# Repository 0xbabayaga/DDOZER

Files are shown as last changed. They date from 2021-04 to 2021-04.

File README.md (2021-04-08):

# DDOZER
Peristaltic dosing pump for DIY. 
Developed firmware is suitable for dosing elements in to the reef aquarium (dosing CA/ALK/MG/NO3/PO4/LiquidFOOD).
Can be easily used for other dosing process.

<b>Technical details:</b>
 - stepper motor & multystep control
 - precise - 0.1ml
 - flow rate (depends on currently option selected) - 6/24/50 ml per minute
 - dimension 52 x 60 x 93mm
 - power 12V DC / 0.2 ... 2.5A (depending on motor type)
 - acrylic body
 - suitable for tubes size from 4 to 5mm outer diameter
 - nonvolatile built-in RTC
 - acryll body (from 2mm thiсkness material)

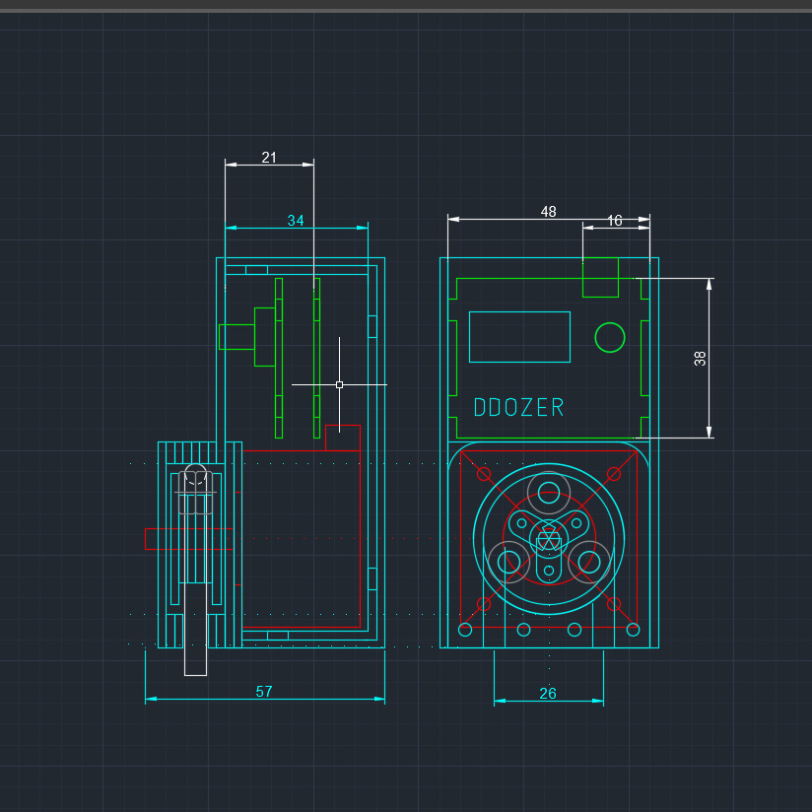
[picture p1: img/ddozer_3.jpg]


<b>Functionality:</b>
 - daily programmble dosign schedule (start dosing time / end dosing time / dosing volume / portions count)
   DDozer automatically divides necessary Volume and dosing interval to Portions count set and doses it evenly. 
   So start first dosage is started at Start Dosing Time & last dosage is completed at the End Dosing Time. Each portion of the volume equal to Dosing Volume / Portions count.     
 - calibration & verify
   User can calbrate and/or verify DDozer any time
 - all DDozer settings saved in nonvolatile memory
 - calculates and saves dosing statistics calculates in nonvolatile memory (daily dosage / total device dosage / total motor hours / last calibration date)
 - daily overdosage protection

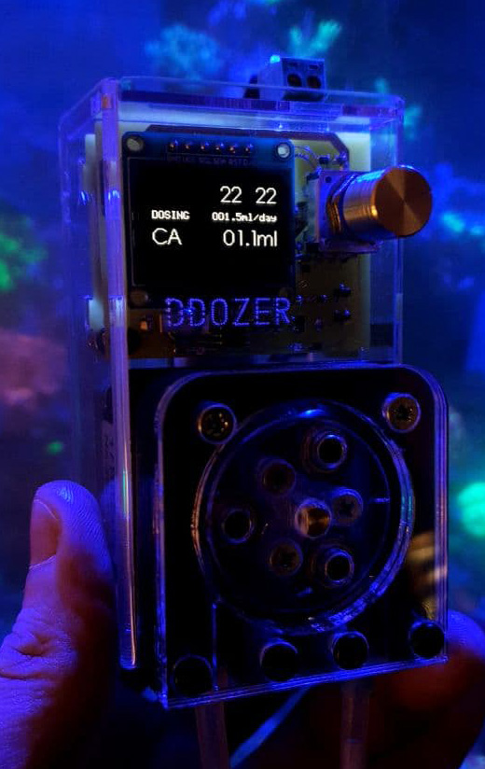
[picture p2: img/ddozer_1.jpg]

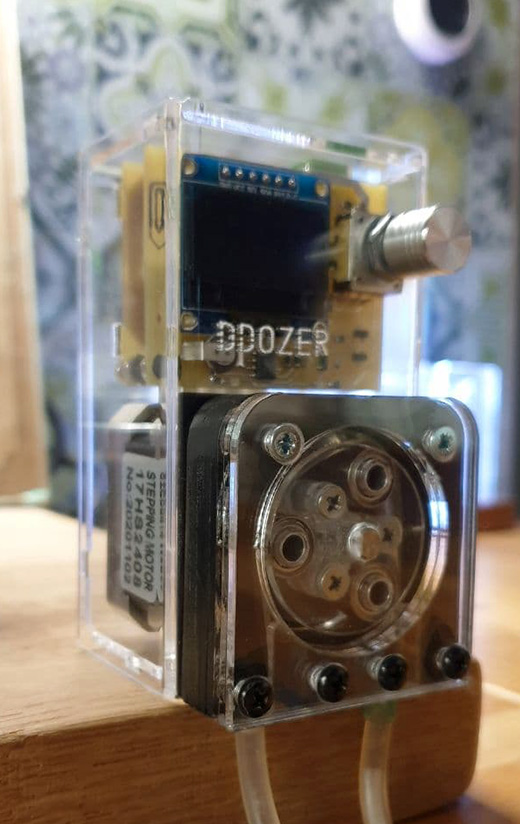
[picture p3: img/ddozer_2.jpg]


Based on STM8S105K4T6C, DRV8825 and SSD1306 OLED display.

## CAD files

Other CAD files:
drawing/DDOZER.dwg

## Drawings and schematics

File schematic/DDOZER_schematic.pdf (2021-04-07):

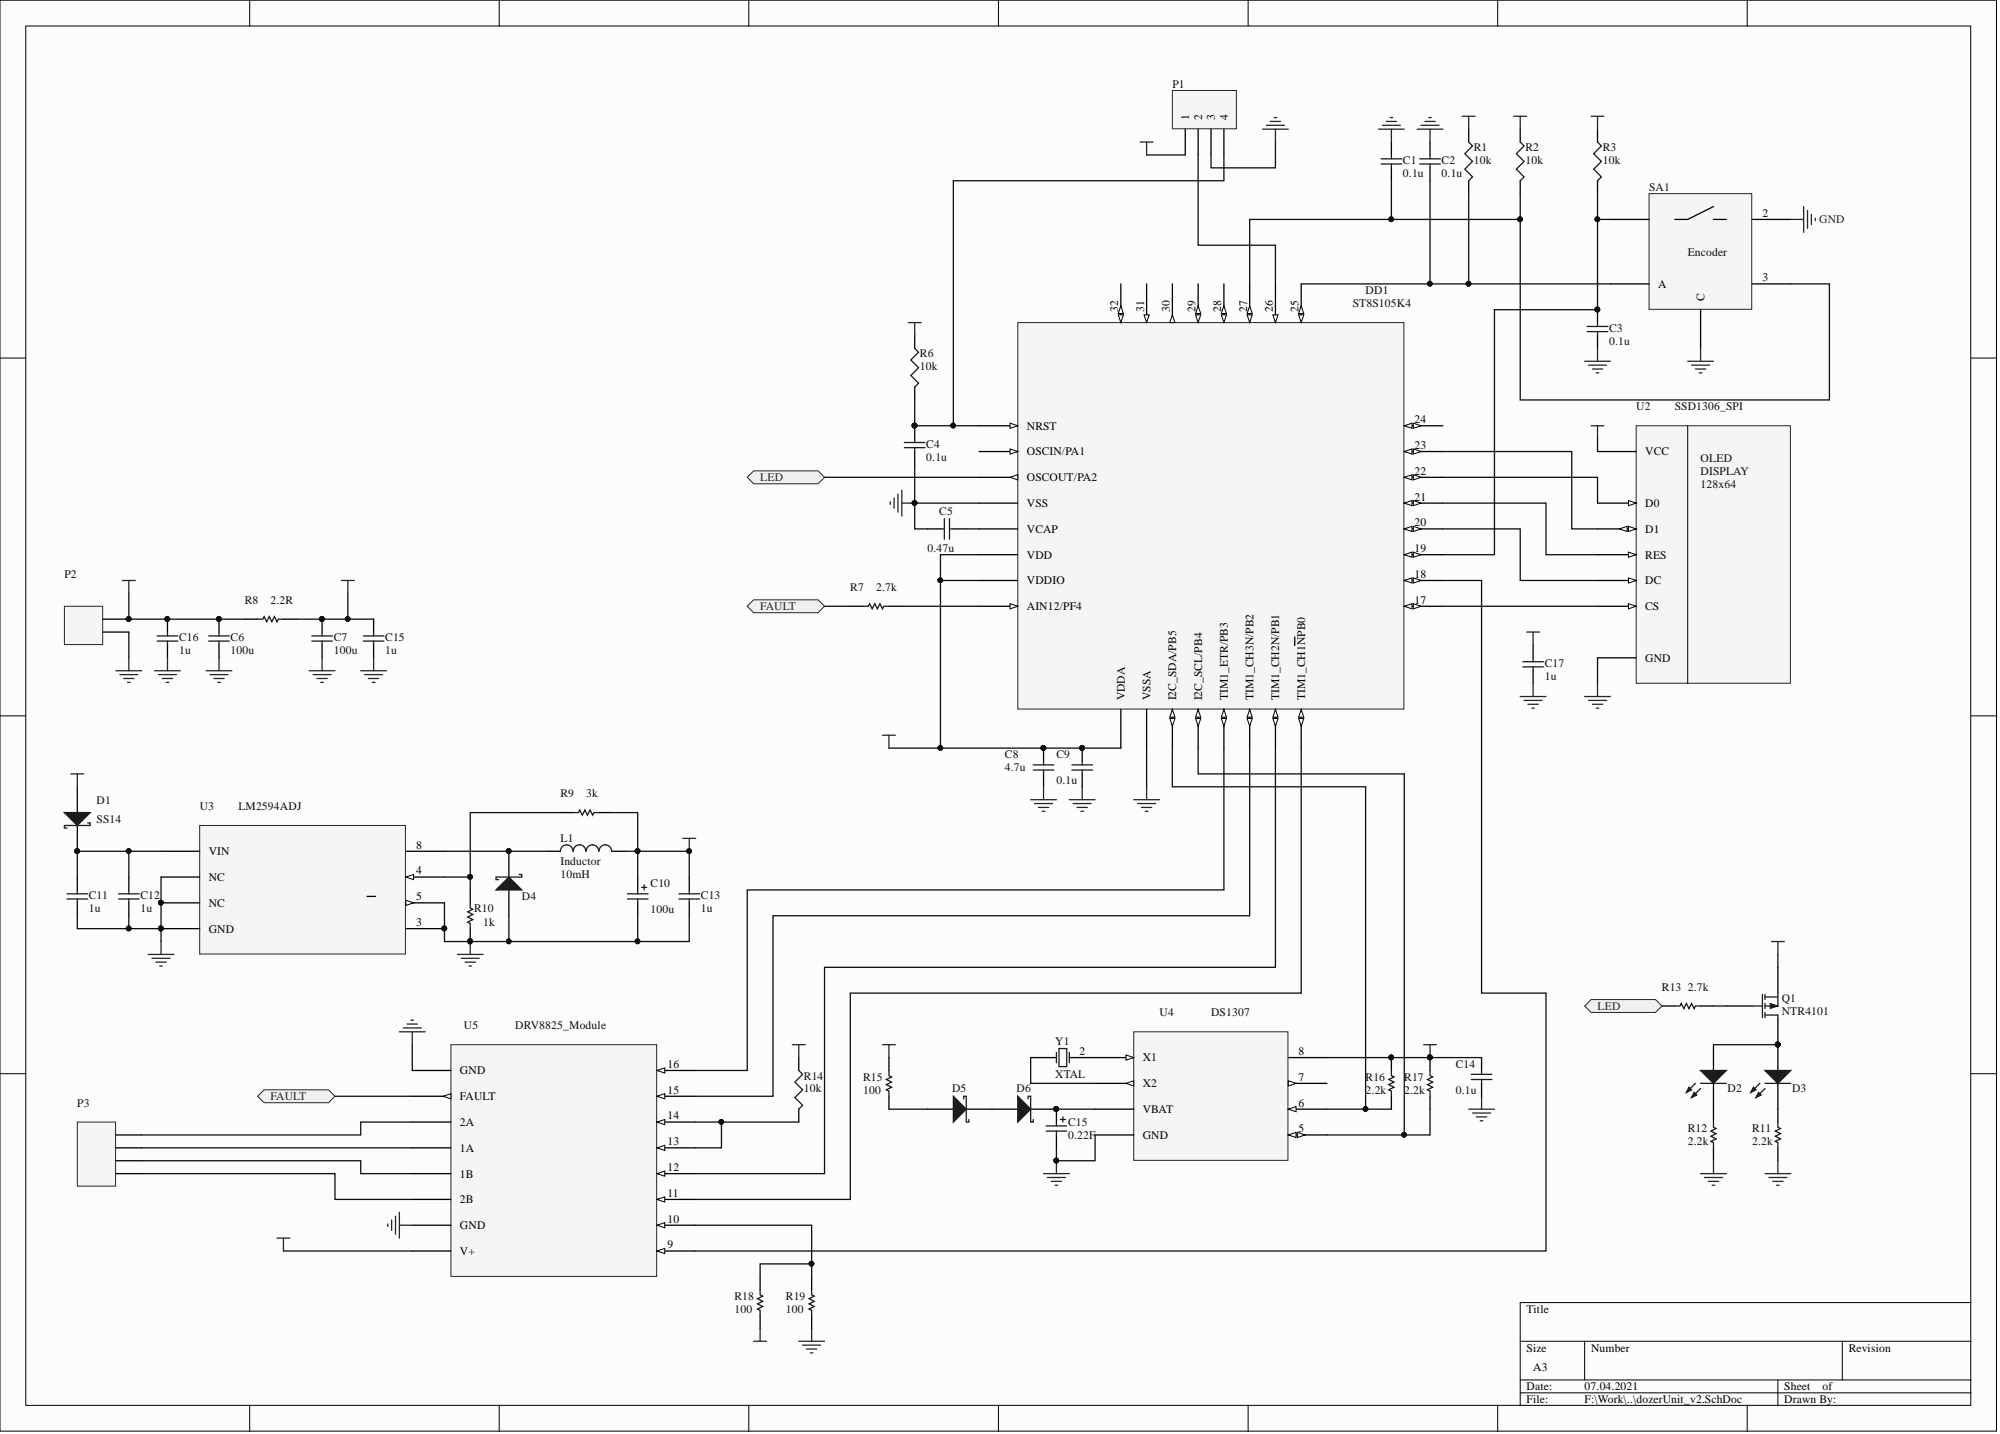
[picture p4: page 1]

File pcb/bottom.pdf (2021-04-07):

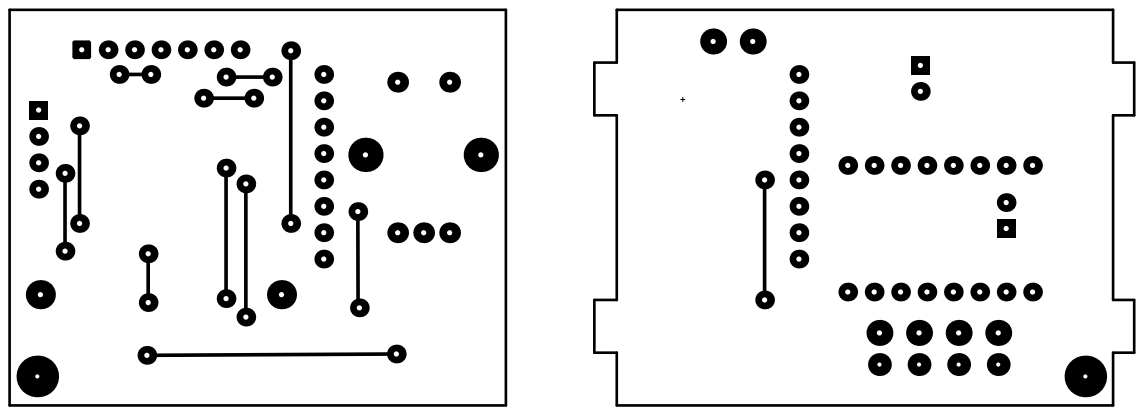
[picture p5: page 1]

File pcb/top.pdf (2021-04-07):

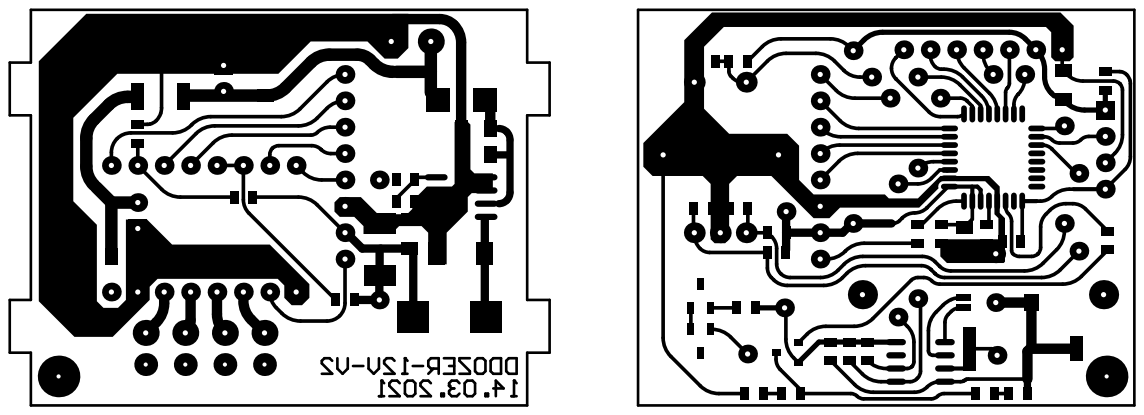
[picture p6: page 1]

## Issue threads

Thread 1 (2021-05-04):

replacement for STM8S105K4T6C

dodolcool, 2021-05-04:
Hello
im interest in building DDOZER really loved the design. the question is can i change the STM8S105K4T6C with the prebuild stm8s? (not the IC version but the prebuild like arduino nano version) since my soldering skill still on beginner and have no luck with the IC smd model.

thanks

Kamal

0xbabayaga, 2021-05-04:
Hello Kamal,

Of course if you re-create the same schematic (connection of MCU to other parts of design) with Arduino Nano STM8S series you will have the same working hardware.

dodolcool, 2021-05-04:
great i will try it soon :) one more question what type of stepper motor did u used?

0xbabayaga, 2021-05-05:
DRV8825 stepper driver allows you to connect a big enough variety of stepper motors.
I have used most popular motor which usually used in 3D-printing like NEMA 17 (1.8) 17HS2408 dimension

dodolcool, 2021-05-18:
thanks for your information. now i have basic question :D what program need to use to upload to stm? i tried with arduino IDE with stm plugin but not work >.<

im sorry for a lots of question

0xbabayaga, 2021-05-19:
Unfortunately i have never used Arduino products so i cannot help you

dodolcool, 2021-05-19:
what compiler program did you use to upload to stm?

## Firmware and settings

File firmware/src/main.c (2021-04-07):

#include "stm8s.h"
#include <stdio.h>
#include "../device/cpuinit.h"
#include "../device/utility.h"
#include "../drivers/ds1307.h"
#include "../drivers/drv8825.h"
#include "../drivers/ssd1306.h"
#include "../device/timers.h"
#include "../device/device.h"
#include "../device/encoder.h"
#include "../device/delay_us.h"
#include "core/task.h"
#include "core/menu.h"

static uint32   rtcReadTick = TIMER_500MS_TMT;
static uint32   menuTick = TIMER_100MS_TMT;
static bool     menuUpdate = TRUE;
static bool     timeChanged = FALSE;
static uint8    lastSecond = 0;

int main( void )
{    
    asm("sim");

    CPU_Init();
    TIM_Init();  
    DRV_Init();
    ENC_Init();
    SSD1306_Init();
    
    DRV_StopMotor();
    
    if (DS1307_init() == FALSE)
        DS1307_init();

    DS1307_readDateTime();

    DEV_ReadCfg();
    DEV_ReadStat(DS1307_getDateTime());
    DRV_SetMotorMode((eMotorSpeedMode) DEV_GetDevOptions()->speedPrecise, (eDir) DEV_GetDevOptions()->dir);

    SSD1306_Clear();
    SSD1306_DrawText16(0, 16, DEVICE_NAME, FALSE, eJustify_Center);
    SSD1306_DrawText8(0, 40, DEVICE_FIRMWARE_VER, eJustify_Center);
    delay_ms(1777);
    SSD1306_Clear();

    task_initActivity();
    resetUpTime();

    asm("rim");
    
    for(;;)
    {      
        /* Reading the system time */
        if (TIM_isTimeoutExpired(rtcReadTick, TIMER_500MS_TMT) == TRUE)
        {
            rtcReadTick = TIM_getSystemTick();
            
            DS1307_readDateTime();

            if (lastSecond != DS1307_getDateTime()->seconds)
            {
                lastSecond = DS1307_getDateTime()->seconds;
                timeChanged = TRUE;
            }
            
            //menuUpdate = TRUE;
        }      
        
        /* Display update */
        if (TIM_isTimeoutExpired(menuTick, TIMER_100MS_TMT) == TRUE)
        {
            menuTick = TIM_getSystemTick();
            menuUpdate = TRUE;
        }
        
        /* Menu handler */
        MENU_Activity(menuUpdate);
        menuUpdate = FALSE;

        if (timeChanged == TRUE)
        {
            task_doserActivity();

            if (DRV_IsMotorRunning() > 0)
                LED_Set(LED_ON);
            else
                LED_Set(LED_OFF);

            timeChanged = FALSE;
        }
        
        delay_ms(1); 
    }
}

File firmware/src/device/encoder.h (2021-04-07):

#ifndef _ENCODER_H
#define _ENCODER_H

#define ENC_QUEUE_SIZE          8
#define ENC_MULTI_STEP2_LEVEL   10
#define ENC_MULTI_STEP10_LEVEL  20

typedef enum _EncKeys
{
    eKeyNone = 0,
    eKeyFwd = 1,
    eKeyFwd2 = 2,
    eKeyFwd10 = 10,
    eKeyBwd = -1,
    eKeyBwd2 = -2,
    eKeyBwd10 = -10,
    eKeyPress = 30,
    eKeyLongPress = 40
}   eEncKey;

void    ENC_Init(void);
eEncKey ENC_getPressedKey(void);

#endif
